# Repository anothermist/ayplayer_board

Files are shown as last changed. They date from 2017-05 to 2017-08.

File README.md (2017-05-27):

# ayplayer_board
В этом хранилище содержатся файлы платы чиптюнового плеера, разработанные в Altium Designer.
Плата разрабатывалась на базе СФУ гор. Красноярска (приобретена лицензия на Altium).
Материалы распространяются "как есть".
Я оставляю за собой право менять содержимое репозитория.
В репозитории chiptune_player_2.22 находится программное обеспечение для этой платы.

Проект состоит из:
Папка doc - в этой папке содержатся схемы в формате pdf, а так же сборочные чертежи.
Папка main_gerber - тут хранятся gerber файлы последней заказанной платы.
Папка main_pcb - тут находятся файлы проекта основной платы для altium.
Папка step - здесь хранятся 3D модели плат.

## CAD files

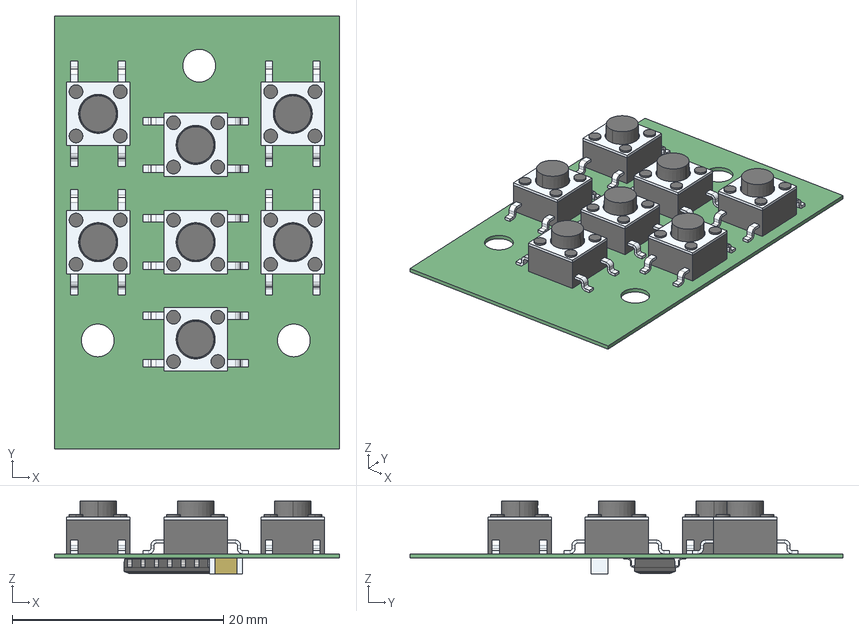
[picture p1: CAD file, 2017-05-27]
step/key.step
27.0 x 41.0 x 6.91 mm
Board
SW3DPS-SO-16-DEFAULT
Extruded x 3
tact_sw_6x6x5 x 7

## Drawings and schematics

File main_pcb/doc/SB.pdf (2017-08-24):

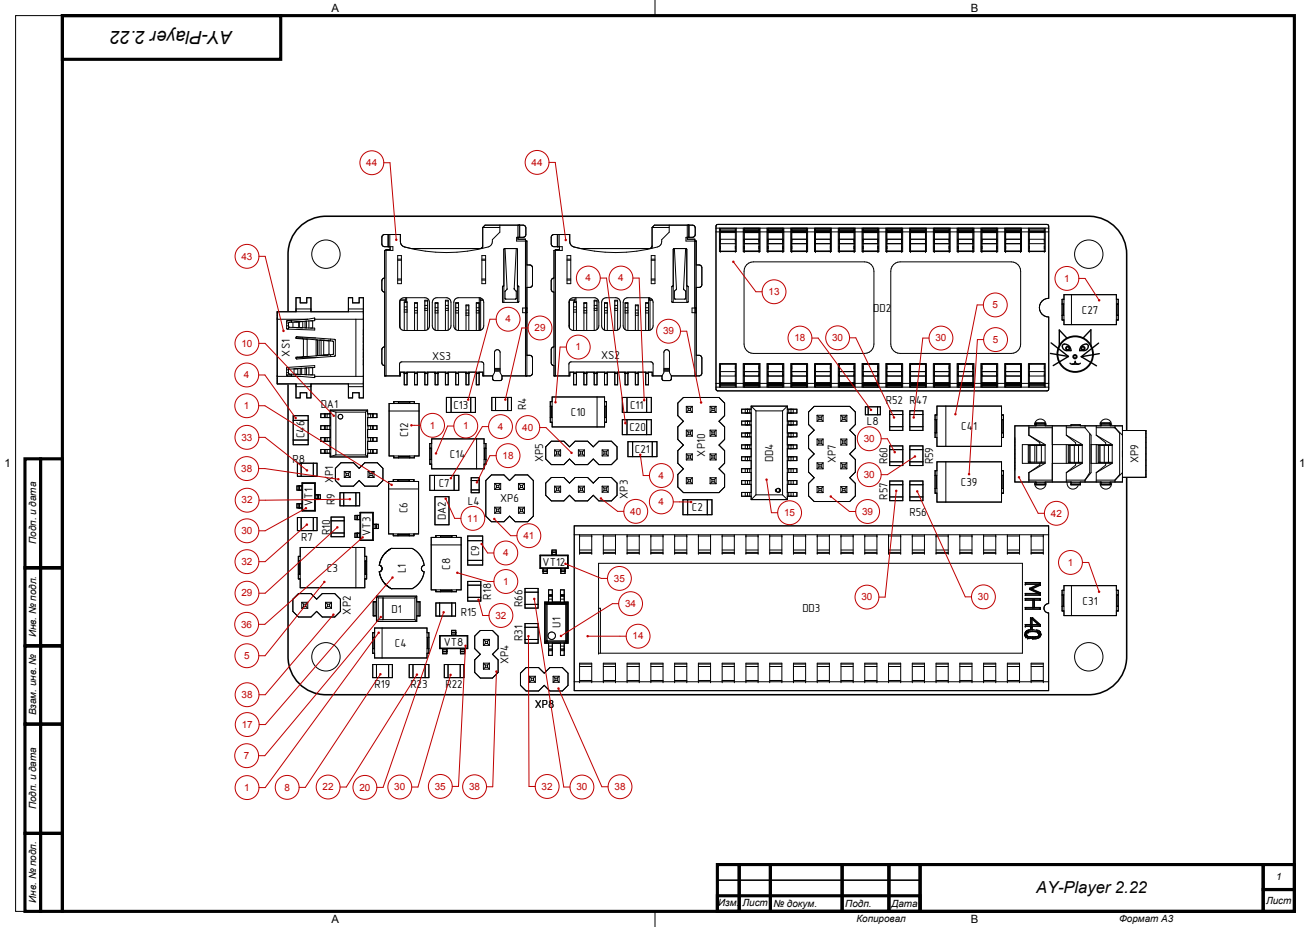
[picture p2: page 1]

Подп. и дата Инв. № подл. Взам. инв. № Подп. и дата Инв. № подл.

## C19C²²

194 4

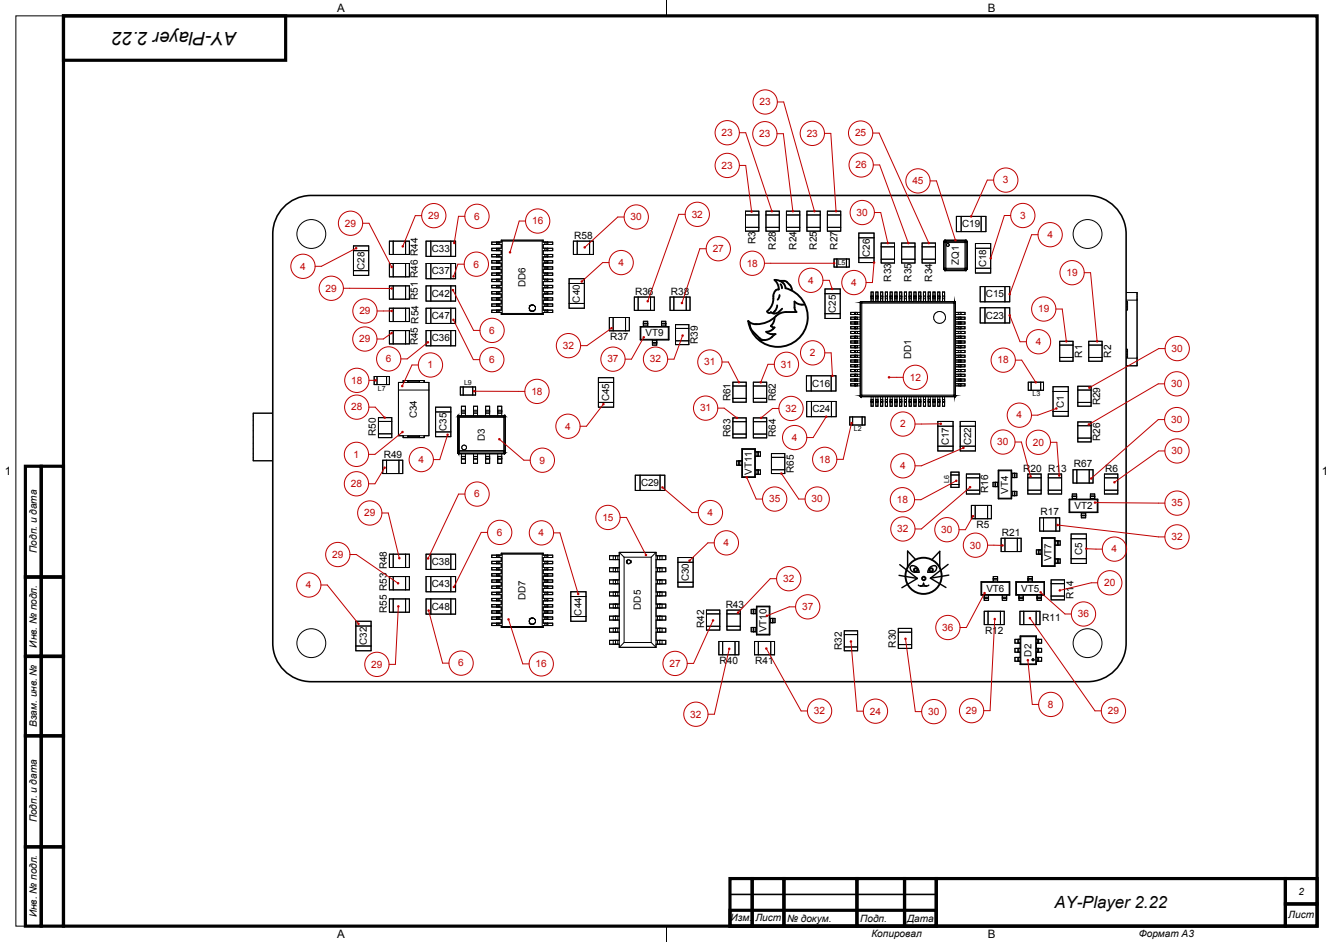
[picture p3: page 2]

Подп. и дата Инв. № подл. Взам. инв. № Подп. и дата Инв. № подл.

A

A

1 | 1
Номер | Обозначение | Компонент | Количество
1 | C4, C6, C8, C10, C12, C14, C27, C31, C34 | 10 мкФ | 9
2 | C16, C17 | 2.2 мкФ | 2
3 | C18, C19 | 6.8 пФ | 2
4 | C1, C2, C5, C7, C9, C11, C13, C15, C20-C26, C28-C30, C32, C35, C40, C44-C46 | 0.1 мкФ | 24
5 | C3, C39, C41 | 100 мкФ | 3
6 | C33, C36-C38, C42, C43, C47, C48 | 1 мкФ | 8
7 | D1 | D SS14 (1n5819) | 1
8 | D2 | PT1301 | 1
9 | D3 | MCP6022 | 1
10 | DA1 | TP4056 | 1
11 | DA2 | NCP551 | 1
12 | DD1 | STM32F205RCT6 | 1
13 | DD2 | AY-3-8912 | 1
14 | DD3 | YM2149 | 1
15 | DD4, DD5 | 74HC595N | 2
16 | DD6, DD7 | AD5204 | 2
17 | L1 | L 4.7 uH | 1
18 | L2-L9 | BLM18AG102SN1 | 8
19 | R1, R2 | 22 Ом | 2
20 | R13-R15 | 10 Ом | 3
21 | R19 | 3 МОм | 1
22 | R23 | 1 МОм | 1
23 | R3, R24, R25, R27, R28 | 47 кОм | 5
24 | R32 | 330 Ом | 1
25 | R34 | 10 МОм | 1
26 | R35 | 390 Ом | 1
27 | R38, R42 | 100 Ом | 2
28 | R49, R50 | 220 Ом | 2
29 | R4, R10-R12, R44-R46, R48, R51, R53-R55 | 4.7 кОм | 12
30 | R5, R6, R20-R22, R26, R29, R30, R33, R47, R52, R56-R60, R65-R67 | 10 кОм | 19
31 | R61-R63 | 0 Ом | 3
32 | R7, R9, R16-R18, R31, R36, R37, R39-R41, R43, R64 | 1 кОм | 13
33 | R8 | 1.2 кОм | 1
34 | U1 | HMHAA280 | 1
35 | VT2, VT4, VT7, VT8, VT11, VT12 | BC817 | 6
36 | VT1, VT3, VT5, VT6 | IRLML6402 | 4
37 | VT9, VT10 | 2N7002 | 2
38 | XP1, XP2, XP4, XP8 | PLS-2 | 4
39 | XP7, XP10 | PLD-8 | 2
40 | XP3, XP5 | PLS-3 | 2
41 | XP6 | PLD-4 | 1
42 | XP9 | Jack_3.5 5-pin | 1
43 | XS1 | USB-mini, тип B | 1
44 | XS2, XS3 | 49225-0821 | 2
45 | ZQ1 | NX3225SA-16.000M-STD-CRS-2 | 1

Подп. и дата Инв. № подл. Взам. инв. № Подп. и дата Инв. № подл.

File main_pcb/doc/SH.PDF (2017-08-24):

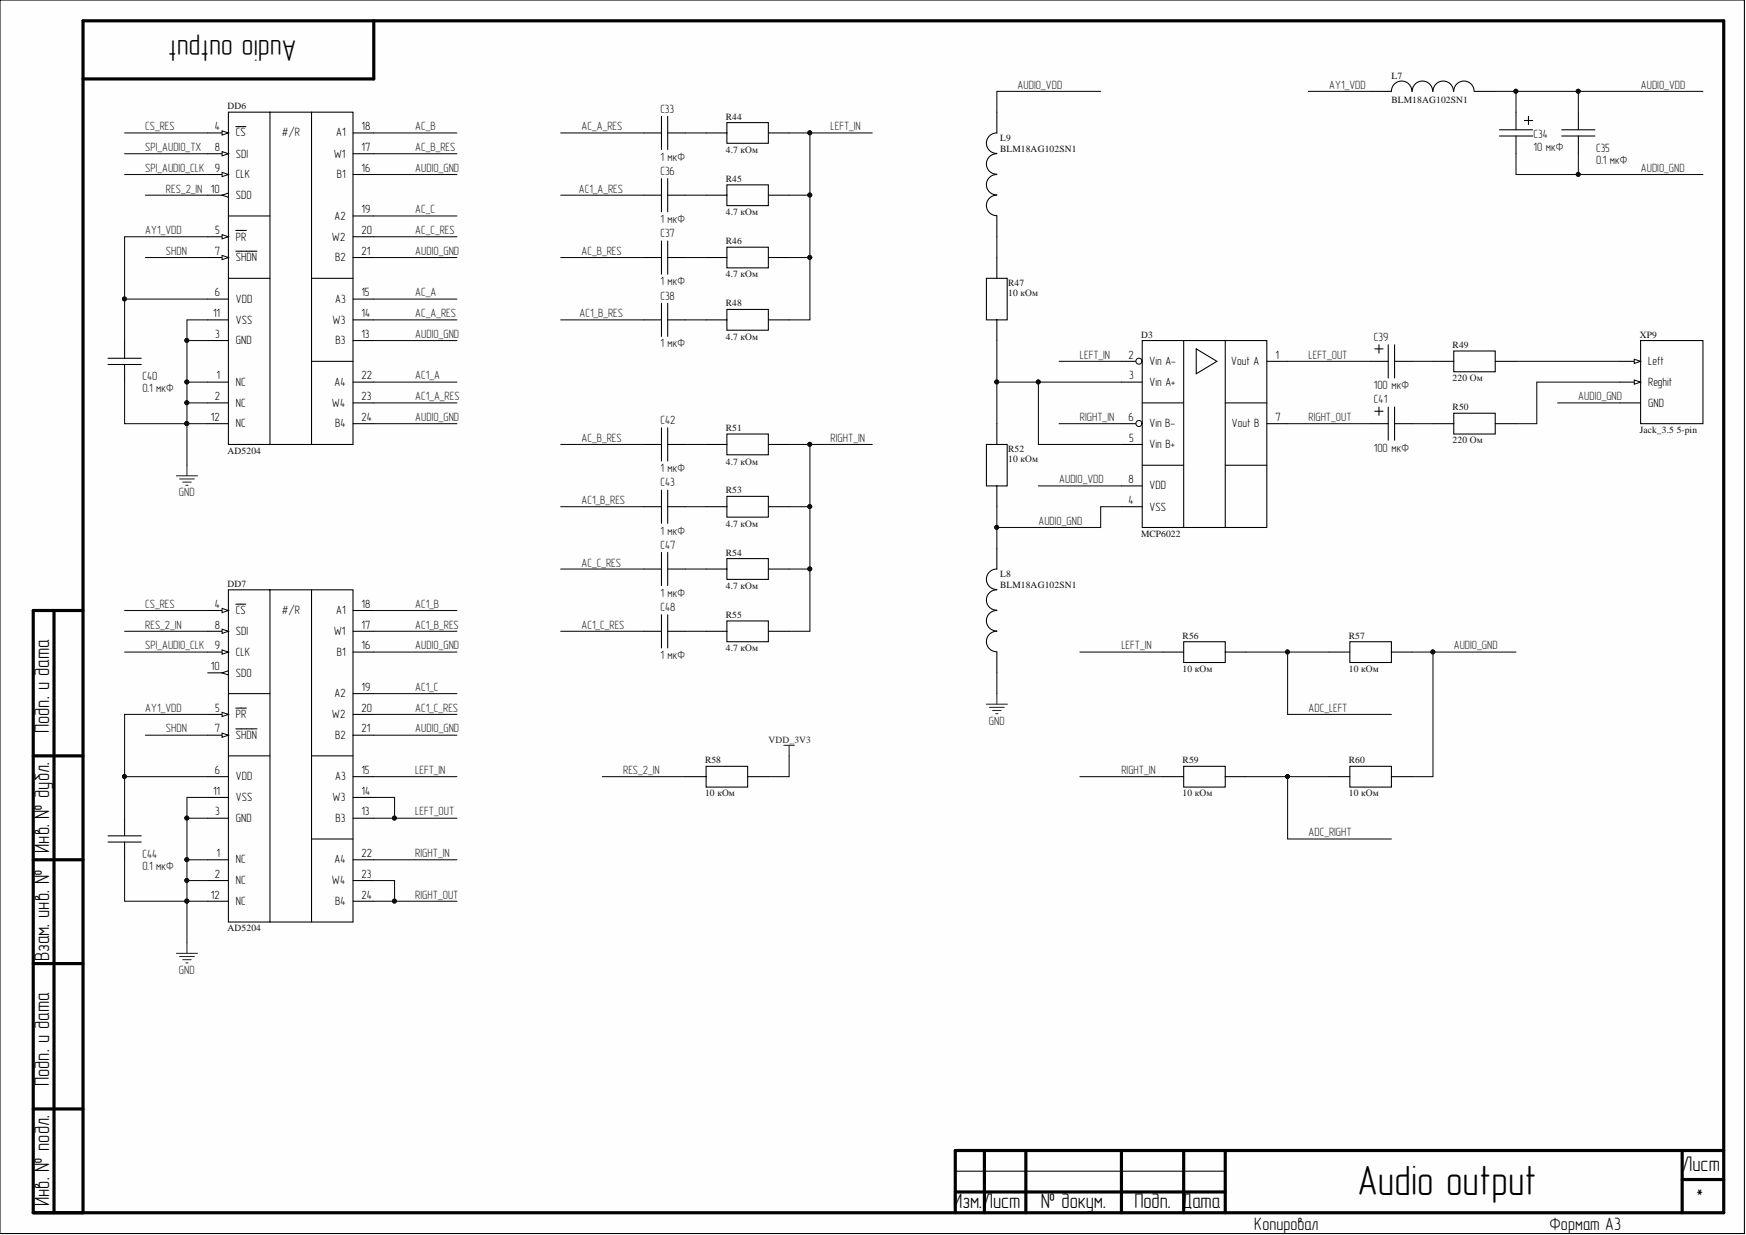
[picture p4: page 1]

* нв. № подл. Инв. № дубл. Подп. и да

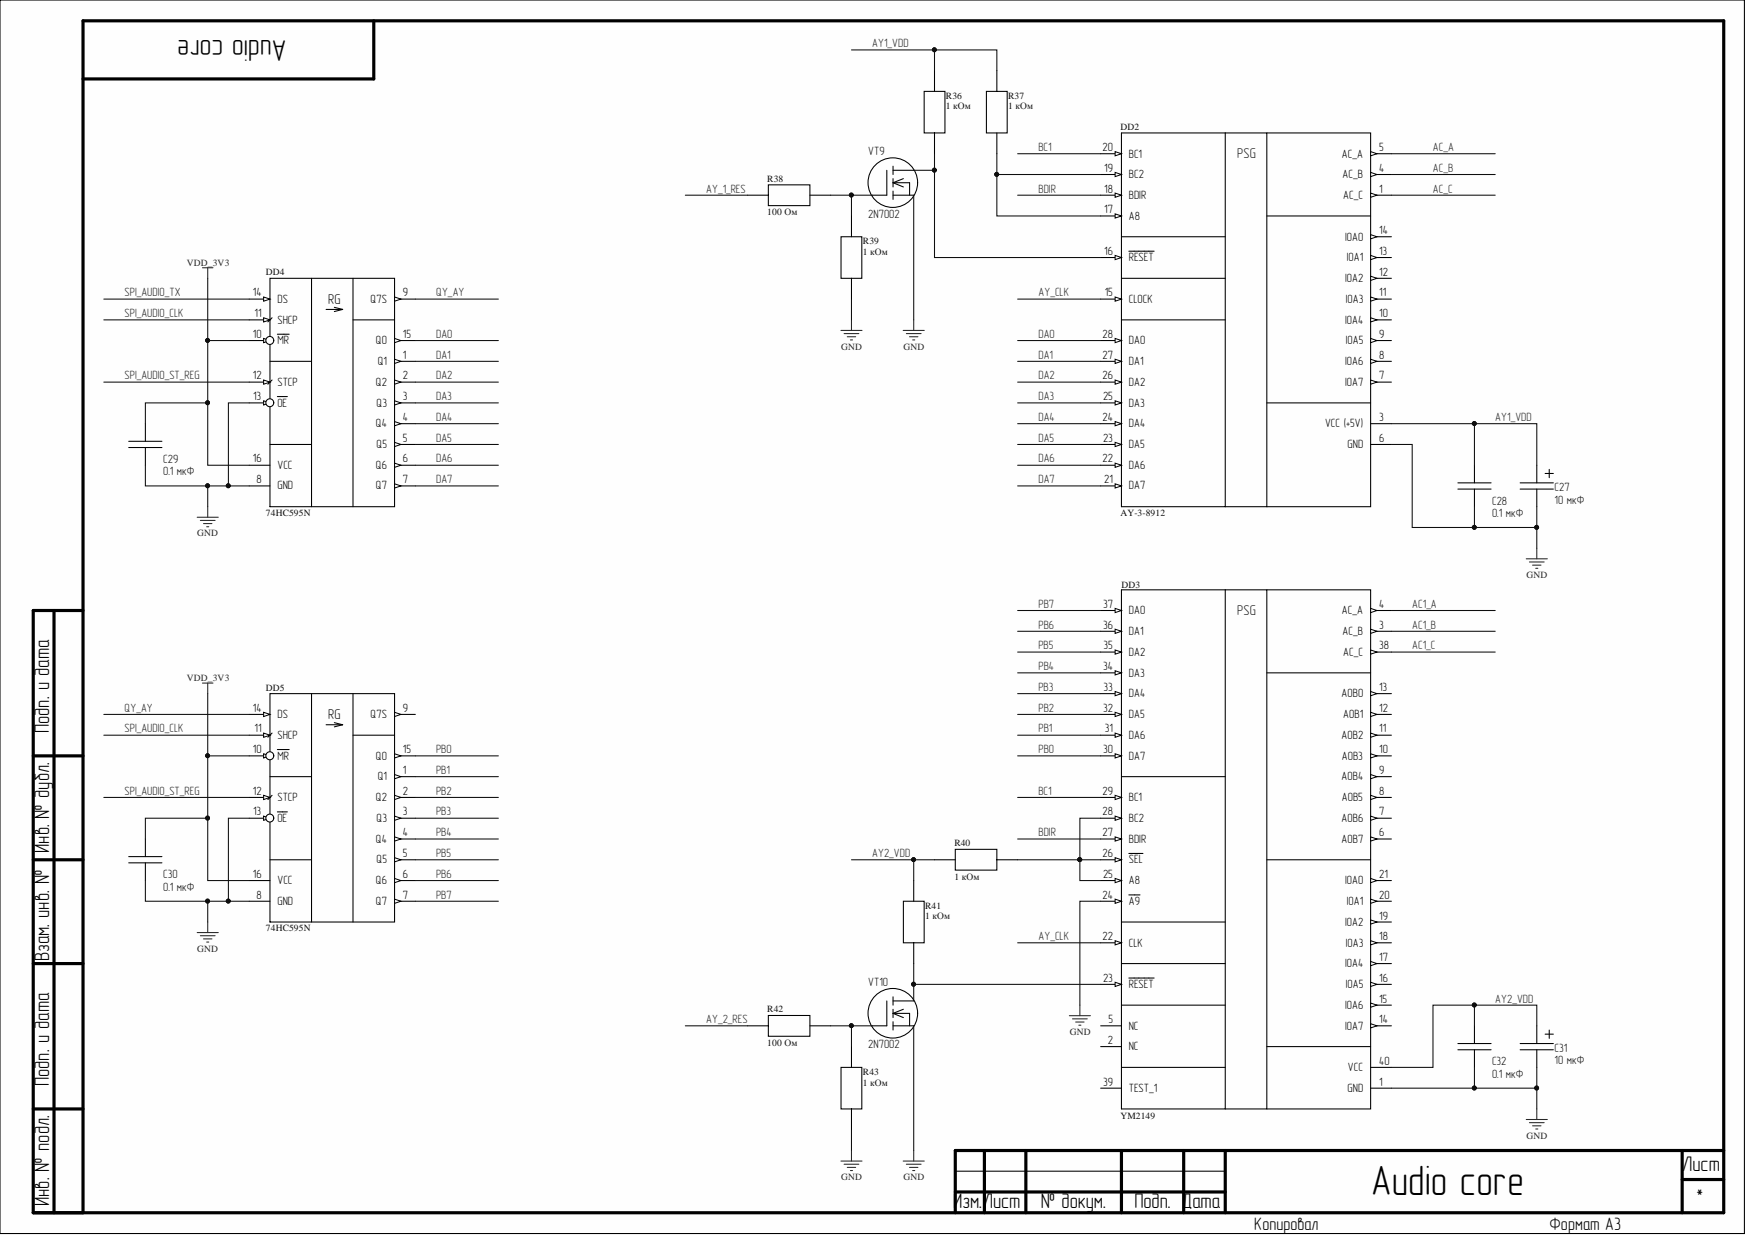
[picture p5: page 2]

BDIR | BDIR 18 A8 17

* нв. № подл. Инв. № дубл. Подп. и да

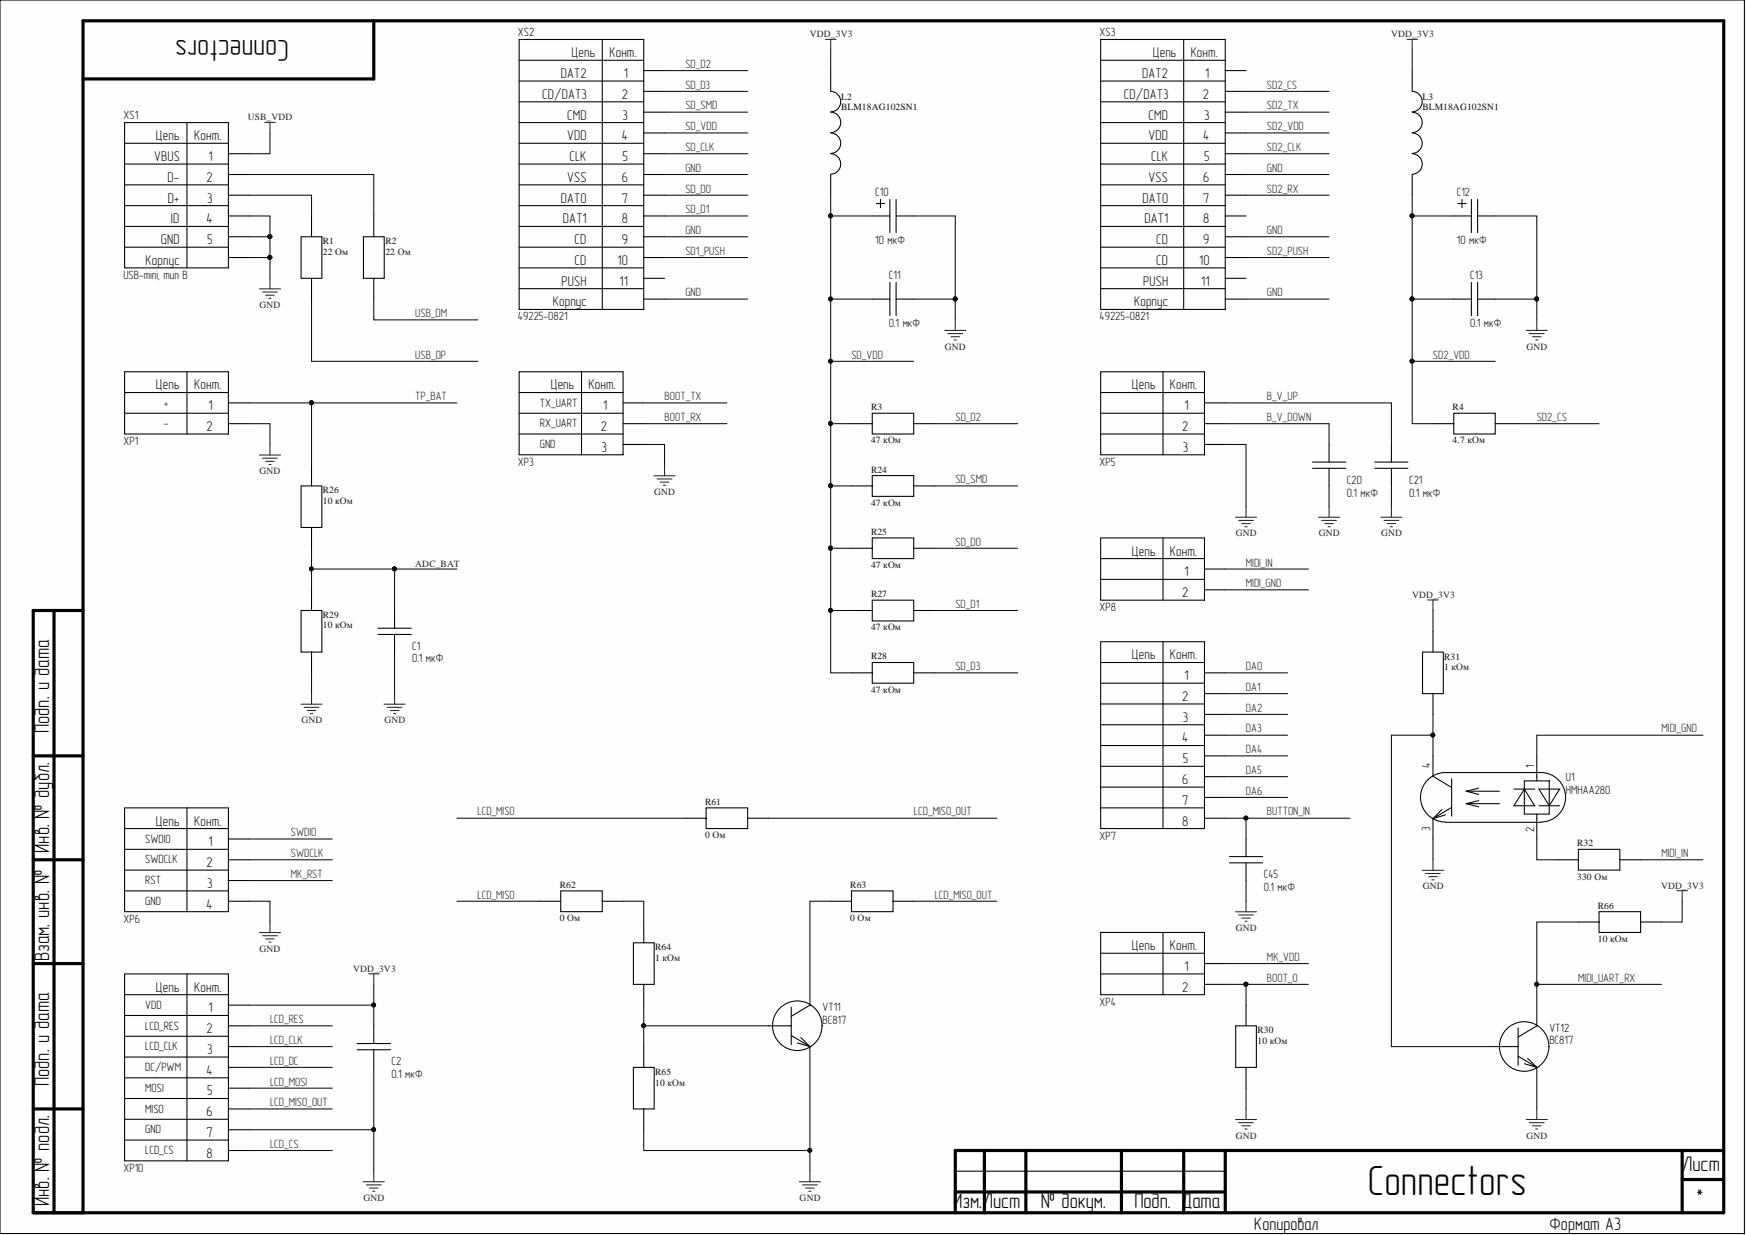
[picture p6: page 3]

Цепь | Конт.

* нв. № подл. Инв. № дубл. Подп. и да

SWDIO | 1
SWDCLK | 2

VDD | 1
LCD_RES | 2
LCD_CLK | 3
4 | LCD_DC DC/PWM

MOSI | 5
MISO | 6

LCD_CS | 8

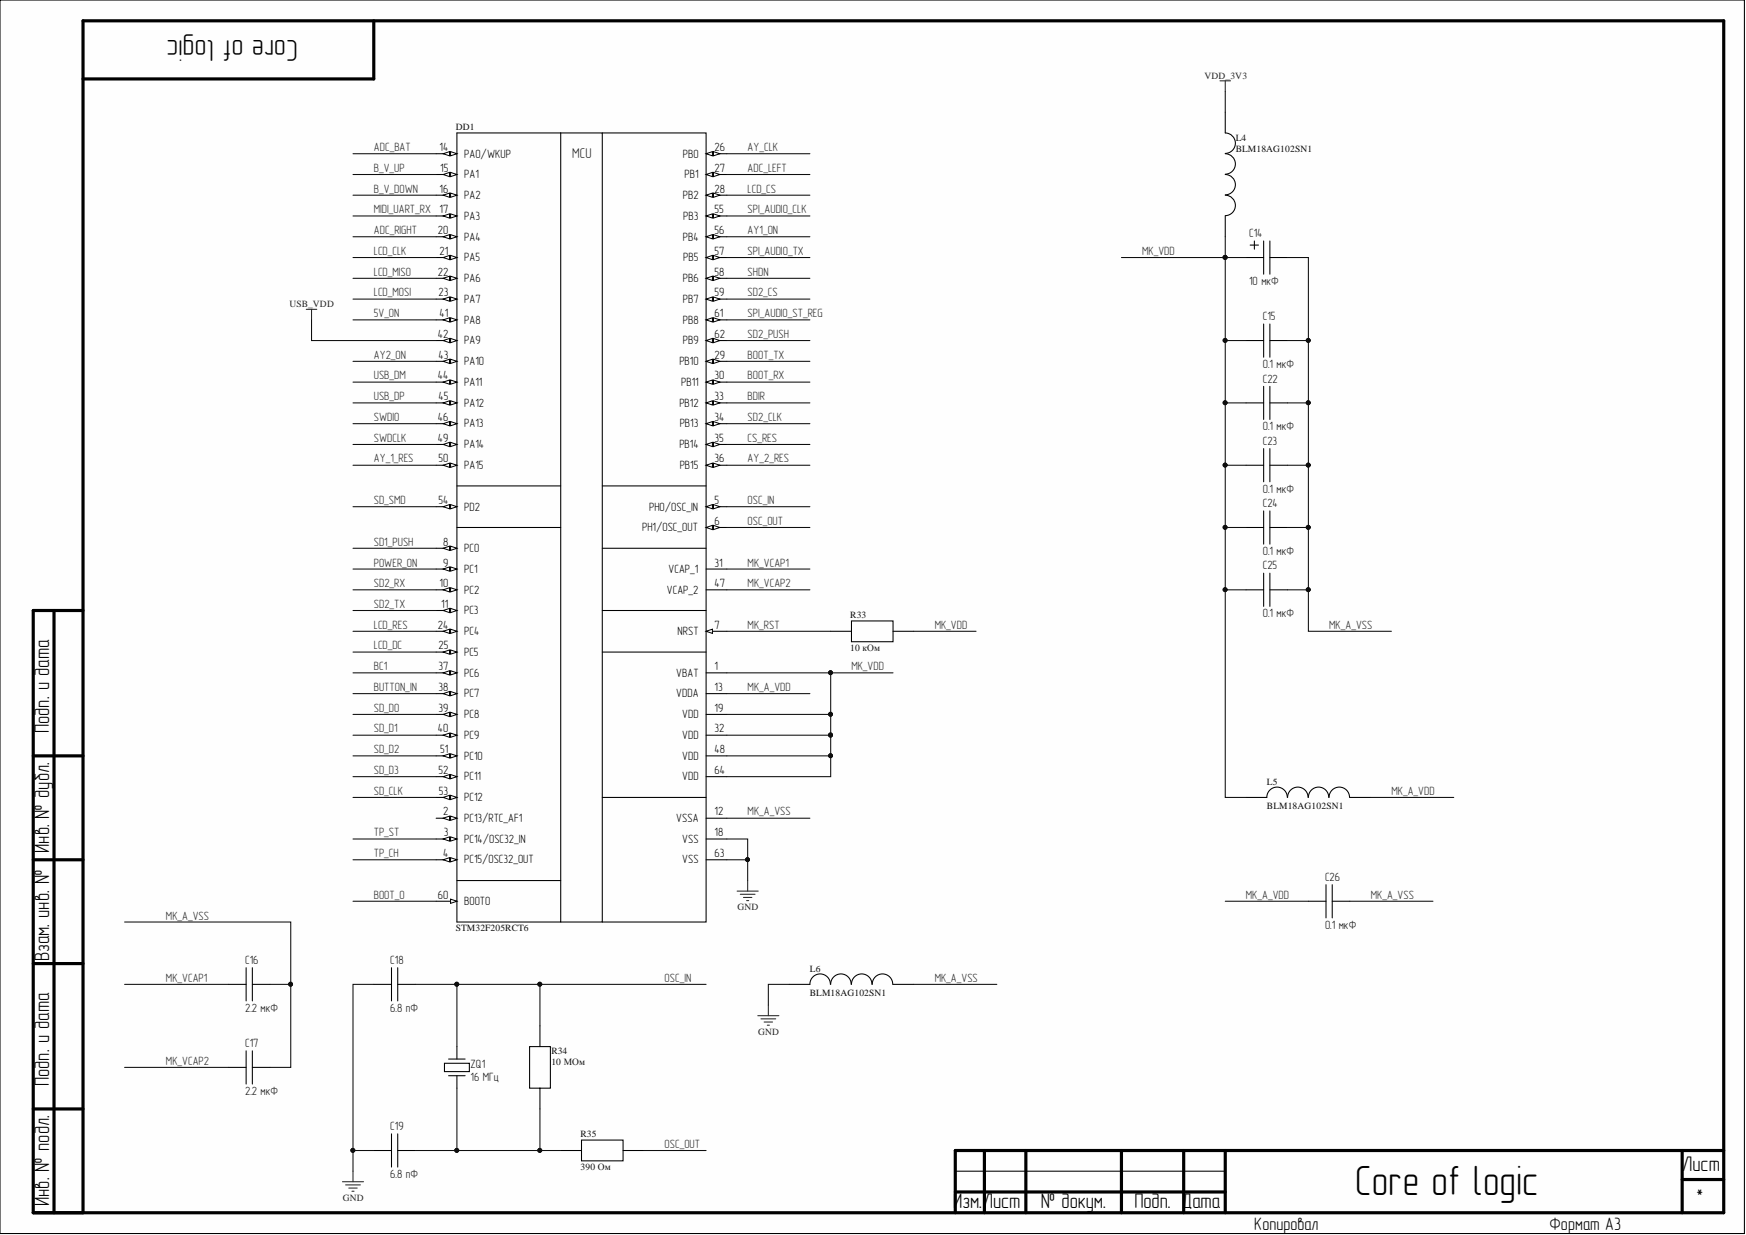
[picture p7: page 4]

* нв. № подл. Инв. № дубл. Подп. и да

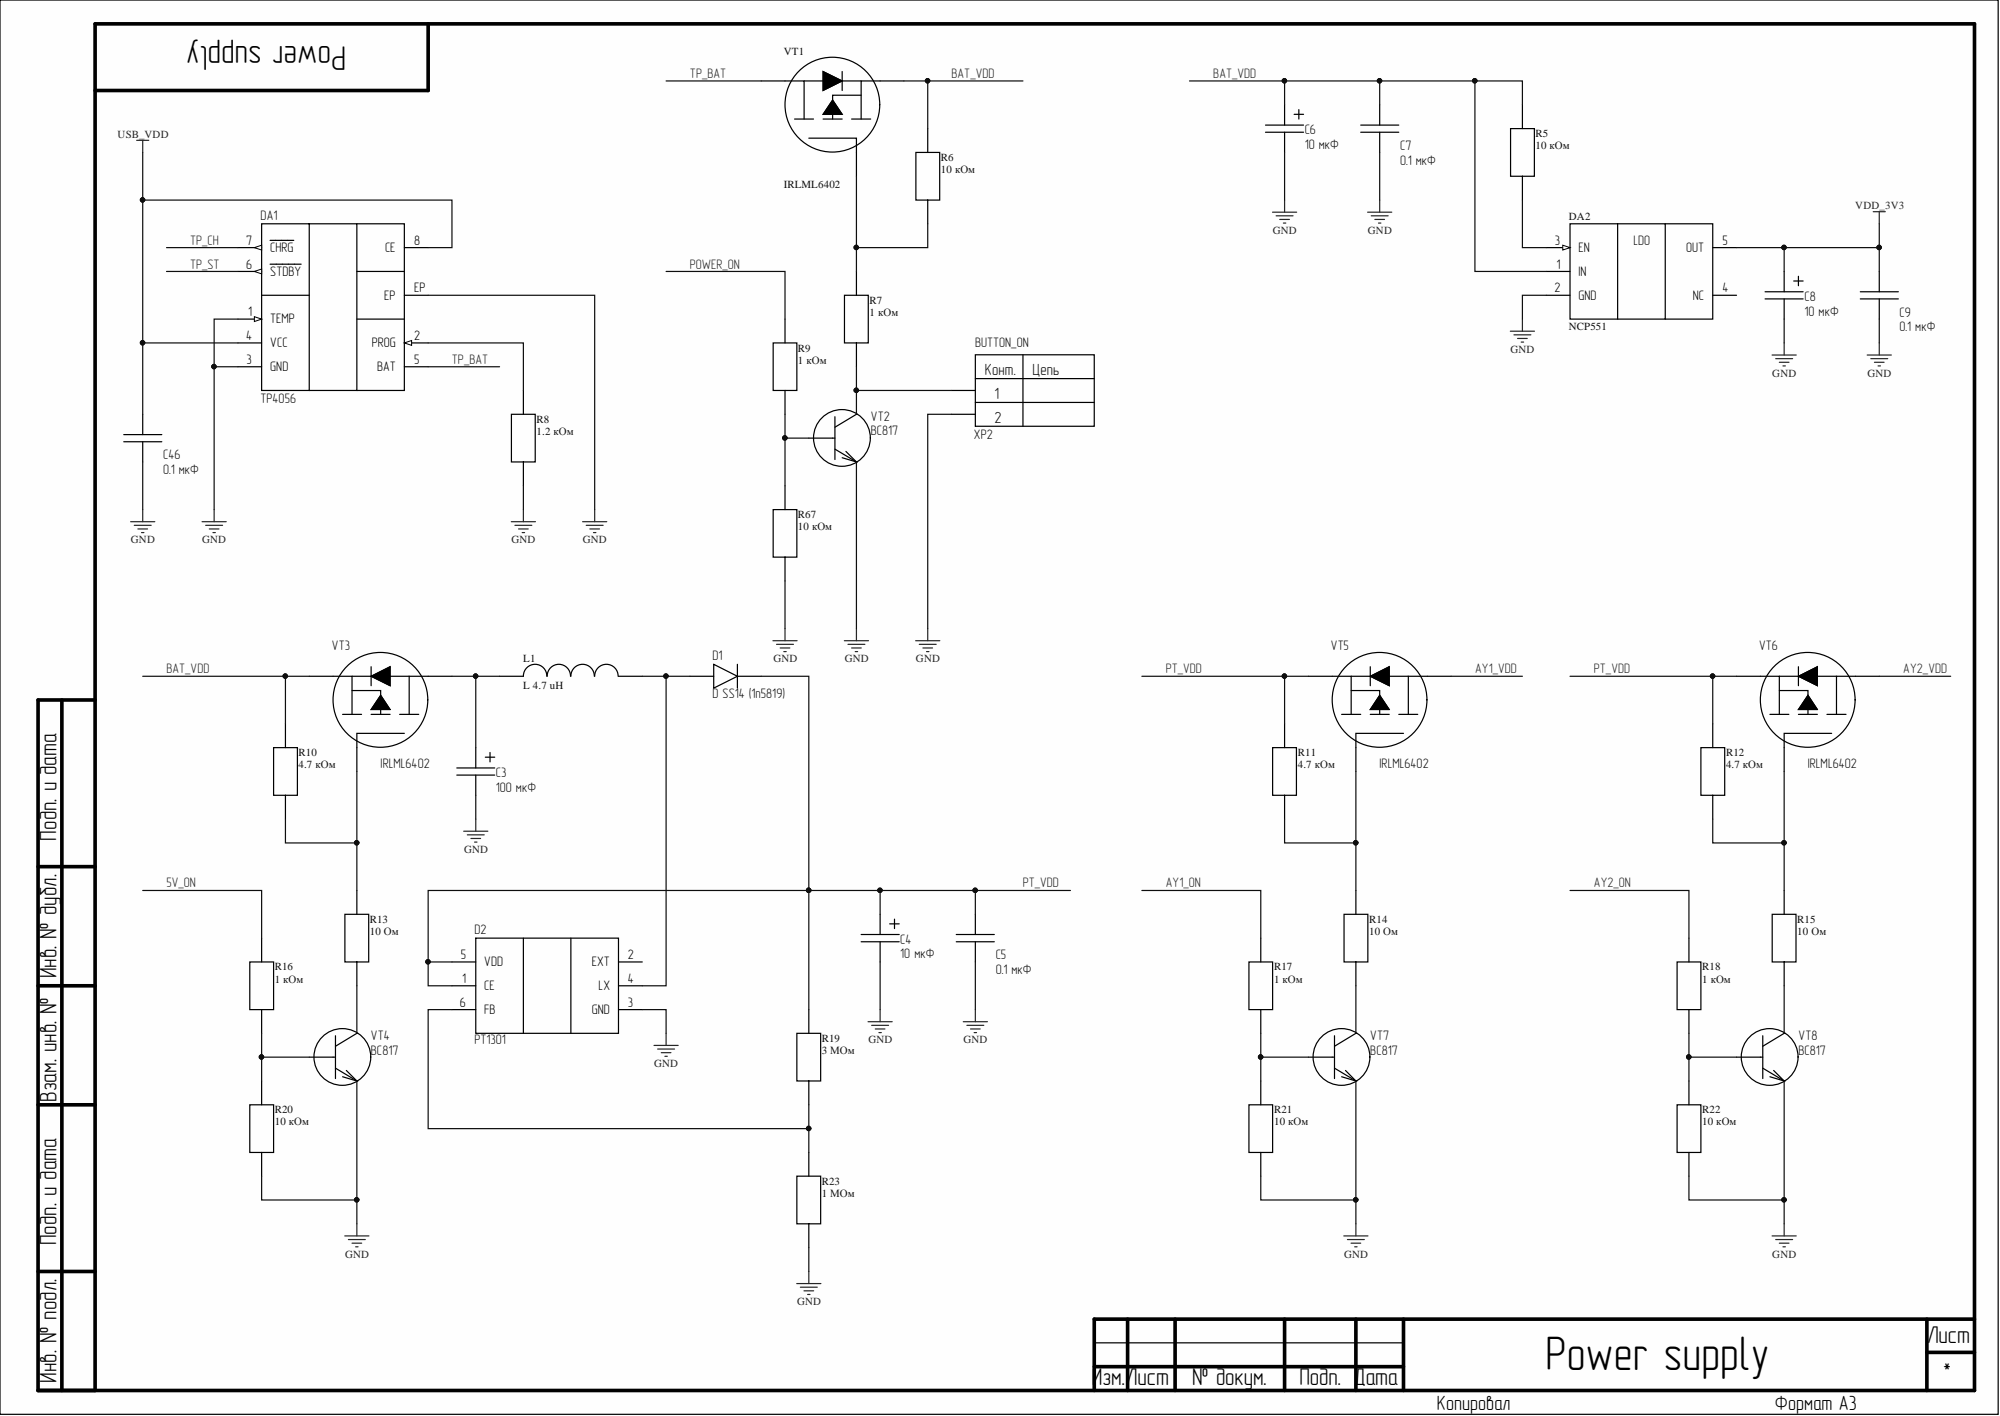
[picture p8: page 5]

Конт. | Цепь

* нв. № подл. Инв. № дубл. Подп. и да

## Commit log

2017-05-27 Обновил описание репозитория.
2017-05-27 Перенесены все файлы проекта в репозиторий.
    [audio_out.SchDoc, audio_sheet.SchDoc, ayplayer2.22.PrjPCB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]
2017-05-27 Описание дополнено.
    [main.GBL, main.GBO, main.GBS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]
2017-05-27 Добавлены файлы платы клавиатуры.
    [ayplayer2.22.PrjPCB, key.step, keys_player.PrjPcb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]
2017-07-11 Добавил gitignore в проект.
2017-07-11 Фикс косяка с неверным подключением потенциометров в блоке микшера на схеме (убрал разделительные конденсаторы). Так же изменил плату (заменил конденсаторы на резисторе в блоке микширования каналов б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
    [audio_out.SchDoc, ayplayer2.22.PrjPCB]
2017-07-11 Начал редактирование draw файла. 60% завершено.
    [ayplayer2.22.PrjPCB]
2017-07-16 Исправил питание потенциометров на плате (теперь от 5V от каждого чипа AY).
    [audio_out.SchDoc, audio_sheet.SchDoc]
2017-07-16 Поправил сборочный чертеж и схему в pdf.
    [ayplayer2.22.PrjPCB, mk.SchDoc]
2017-07-16 Включил библиотеку с компонентами под altium в основной проект аппаратной части.
2017-08-24 Заказанная версия (с котом).
    [audio_out.SchDoc, audio_sheet.SchDoc, ayplayer2.22.PrjPCB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]
2017-08-24 Обновил PDF файлы (сборочник + схема) под реализацию платы для радиокота.
2017-09-21 Версия с <<котом и лисичкой>> на радиокот.
    [ayplayer2.22.PrjPCB, keys_player.PrjPcb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]
2017-09-21 Добавлена step модель корпуса.
